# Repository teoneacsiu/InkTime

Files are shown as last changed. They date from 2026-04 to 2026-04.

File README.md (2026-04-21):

# InkTime

Smartwatch open-source bazat pe **nRF52840**, proiectat pentru cursul TSC. Acest repository contine partea de hardware, manufacturing si integrare mecanica pentru varianta **InkTime**.

---

## Structura repository-ului

```text
Hardware/
  - schematic (.sch)
  - board (.brd)

Manufacturing/
  - gerbers.zip
  - Bill of Materials (.bom / .csv)
  - Pick and Place (.cpl)

Mechanical/
  - ansamblu complet (.step)
  - fisierul Fusion360 al ansamblului complet

Images/
  - randari PCB
  - randari assembly
  - capturi schematic / board

LICENSE
README.md
```

---

## Stare proiect

- [x] structura repo
- [x] README completat
- [x] BOM de documentatie pentru componentele critice
- [x] schematic complet
- [x] ERC curat
- [x] board complet
- [x] DRC cu fisierul oficial
- [x] gerbers / BOM / CPL exportate
- [ ] model 3D complet: PCB + baterie + display + shaker + carcasa
- [ ] review DVT
- [ ] fix-uri pentru GNG

---

## Block diagram

```mermaid
flowchart LR
    USB[USB-C]
    ESD[USB ESD Protection]
    PMIC[BQ25180YBGR\nLi-Ion Charger + Power Path]
    DCDC[RT6160AWSC\nBuck-Boost 3V3]
    MCU[nRF52840\nBLE SoC]
    IMU[BMA421/BMA423\nAccelerometer]
    FG[MAX17048G+T10\nFuel Gauge]
    HAPTIC[DRV2605YZFR\nHaptic Driver]
    EPDPWR[E-Paper Power Stage]
    EPD[24-pin E-Paper FPC]
    BTN[3 Buttons]
    SWD[SWD Header / Test Pads]
    ANT[2.4 GHz Chip Antenna]
    BAT[Li-Po Battery]

    USB --> ESD --> MCU
    USB --> PMIC
    BAT --> PMIC
    BAT --> FG
    PMIC --> DCDC
    DCDC --> MCU
    DCDC --> IMU
    DCDC --> FG
    DCDC --> HAPTIC
    DCDC --> EPDPWR
    MCU <-->|I2C| IMU
    MCU <-->|I2C| PMIC
    MCU <-->|I2C| FG
    MCU <-->|I2C| HAPTIC
    MCU -->|SPI + control| EPDPWR
    EPDPWR --> EPD
    MCU --> BTN
    MCU --> SWD
    MCU --> ANT
```

---

## Arhitectura hardware

### 1. Microcontroller + radio
Controllerul principal este **nRF52840** in capsula QFN/AQFN, folosit pentru:
- controlul intregului sistem;
- comunicare BLE;
- interfata USB;
- I2C pentru PMIC / IMU / fuel gauge / haptic;
- SPI + semnale de control pentru display-ul e-paper;
- SWD pentru debug si programare.

Blocul radio foloseste:
- cristal de **32 MHz** pentru radio;
- cristal de **32.768 kHz** pentru timp real / low power;
- retea de adaptare RF;
- antena chip **2450AT18B100E**.

### 2. Alimentare
Alimentarea este impartita in doua etape:
- **BQ25180YBGR** pentru incarcarea bateriei Li-Po si power-path;
- **RT6160AWSC** pentru generarea tensiunii principale de **3V3**.

Aceasta separare permite:
- alimentare din USB;
- incarcare baterie;
- distributie stabila de 3V3 pentru MCU si periferice.

### 3. Senzori si periferice
- **BMA421/BMA423** - accelerometru low-power pentru detectie miscare / gesturi;
- **MAX17048G+T10** - fuel gauge pentru estimarea starii bateriei;
- **DRV2605YZFR** - driver haptic pentru feedback tactil;
- **E-paper connector + drive stage** - interfata catre display-ul principal;
- **3 butoane** - interfata fizica utilizator;
- **USB-C + ESD** - alimentare si comunicare USB.

---

## Interfete si mapare pini nRF52840

| Functie | Net / semnal | Pin nRF52840 | Motiv |
|---|---|---:|---|
| I2C data | SDA | P0.06 | magistrala comuna pentru PMIC, IMU, fuel gauge, haptic |
| I2C clock | SCL | P0.07 | magistrala comuna pentru PMIC, IMU, fuel gauge, haptic |
| PMIC interrupt | PMIC_INT | P0.11 | evenimente incarcare / power-path |
| IMU interrupt 1 | IMU_INT1 | P0.08 | semnal de intrerupere de la accelerometru |
| IMU interrupt 2 | IMU_INT2 | P1.08 | al doilea semnal de intrerupere de la accelerometru |
| Haptic enable / trigger | HAPTIC_EN | P0.12 | controlul driverului DRV2605 |
| Fuel gauge alert | ALERT | P0.10 / NFC2 | semnal alerta baterie / SOC |
| USB VBUS detect | VBUS | VBUS pin dedicat | detectare prezenta USB |
| USB data minus | D- | D- pin dedicat | USB 2.0 |
| USB data plus | D+ | D+ pin dedicat | USB 2.0 |
| Display chip select | EPD_CS | P0.05 | selectare SPI pentru e-paper |
| Display data/command | EPD_DC | P0.15 | diferentiere date/comenzi |
| Display busy | EPD_BUSY | P0.16 | status busy din display |
| Display reset | EPD_RST | P0.17 | reset hardware display |
| User button UP | SW_UP | P1.15 | input utilizator |
| User button ENTER | SW_ENT | P0.14 | input utilizator |
| User button DOWN | SW_DN | P1.02 | input utilizator |
| E-paper power enable | GPIO pentru Q1 | P1.01 | comanda alimentarea blocului e-paper |
| SWD data | SWDIO | SWDIO pin dedicat | debug/programare |
| SWD clock | SWDCLK | SWDCLK pin dedicat | debug/programare |
| Trace / debug | SWO | GPIO debug | punct de test pentru debugging |

### Observatii pe maparea pinilor
- Magistrala **I2C** este comuna si reduce numarul total de pini ocupati.
- Interfata USB foloseste pinii dedicati ai nRF52840 pentru compatibilitate corecta.
- Semnalele catre e-paper sunt separate intre control (`EPD_CS`, `EPD_DC`, `EPD_RST`, `EPD_BUSY`) si alimentare.
- Butoanele sunt conectate pe GPIO-uri separate pentru tratare simpla in firmware.
- Semnalele de debug sunt expuse atat prin conectorul SWD, cat si prin test pad-uri.

---

## Functionalitatea fiecarui bloc

### nRF52840
- MCU principal;
- BLE;
- USB FS;
- interfete I2C / SPI / GPIO;
- control low-power.

### BQ25180YBGR
- incarcare baterie Li-Ion/LiPo;
- power-path management;
- monitorizare si configurare prin I2C.

### RT6160AWSC
- buck-boost I2C-programmable;
- genereaza 3V3 din sursa sistemului;
- mentine tensiunea stabila pentru subsisteme.

### BMA421/BMA423
- accelerometru digital ultra-low-power;
- detectare miscare / activitate;
- intreruperi dedicate catre MCU.

### MAX17048G+T10
- fuel gauge pentru baterie LiPo;
- masoara tensiunea si estimeaza state-of-charge;
- alerta low battery catre MCU.

### DRV2605YZFR
- driver haptic pentru actuator ERM/LRA;
- controlabil prin I2C;
- permite feedback tactil complex.

### USB-C + ESD
- alimentare si date USB;
- rezistente de configurare CC;
- protectie ESD pe D+/D-/VBUS.

### E-paper drive + connector
- conector FPC de 24 pini;
- etapa de alimentare si comanda pentru display;
- linii SPI/control catre MCU.

---

## BOM de documentatie

BOM-ul de mai jos contine **componentele critice**. Pentru BOM-ul complet de productie trebuie folosit exportul din Fusion/EAGLE.

| RefDes | Componenta | MPN | Qty | Observatii |
|---|---|---|---:|---|
| U1 | BLE SoC | NRF52840-QIAA-R / QIAA-T | 1 | MCU principal |
| IC1 | Charger + power path | BQ25180YBGR | 1 | management baterie |
| IC9 | Buck-boost converter | RT6160AWSC | 1 | 3V3 principal |
| IC3 | IMU | BMA421 / BMA423 | 1 | biblioteca folosita contine BMA423 |
| U3 | Fuel gauge | MAX17048G+T10 | 1 | monitorizare baterie |
| IC2 | Haptic driver | DRV2605YZFR | 1 | control vibratii |
| J4 | USB-C | KH-TYPE-C-16P | 1 | alimentare + USB |
| D3 | ESD USB | USBLC6-2SC6Y | 1 | protectie D+/D-/VBUS |
| J1 | E-paper FPC | 503480-2400 | 1 | conector display |
| ANT1 | Chip antenna 2.4 GHz | 2450AT18B100E | 1 | BLE antenna |
| J2 | SWD header | TC2030-IDC | 1 | programare / debug |
| D2,D4,D5 | Schottky diode | MBR0530 | 3 | bloc power e-paper |
| Q3 | N-MOS | SI1308EDL-T1-GE3 | 1 | drive e-paper |
| Q1 | P-MOS | DMG2305UX-7 | 1 | comutare alimentare e-paper |
| X1 | RF crystal | 32MHz | 1 | ceas radio |
| X2 | RTC crystal | 32.768kHz | 1 | low-power timing |
| L7 | Inductor DCDC | FTC252012SR47MBCA | 1 | buck-boost RT6160 |
| SW_UP, SW_ENT, SW_DN | Butoane tactile | TBD | 3 | verificare finala dupa layout |
| Battery | Li-Po battery | TBD | 1 | model 3D de desenat |
| Display | E-paper module | TBD | 1 | model 3D de desenat |
| Shaker | ERM/LRA actuator | TBD | 1 | model 3D de desenat |

### Observatii BOM
- Toate rezistentele sunt SMD 0201.
- Toate condensatoarele cu valori `<= 100nF` sunt SMD 0201.
- Condensatoarele cu valori `> 100nF` sunt 0402, cu exceptiile specificate explicit in schema.
- BOM-ul din README este un BOM de documentatie; BOM-ul final de productie va fi exportat direct din CAD.

---

## Design rules si constrangeri care trebuie respectate

### PCB / mechanical
- grosime PCB: **1.0 mm**;
- componentele se amplaseaza **exclusiv pe TOP**;
- rutarea poate fi pe TOP si BOTTOM;
- trebuie **plan de masa pe TOP si pe BOTTOM**;
- daca se folosesc 4 straturi, unul dintre straturile interne trebuie sa fie GND;
- PCB-ul trebuie sa intre in carcasa furnizata;
- USB-C, butoanele si conectorul display trebuie aliniate mecanic cu carcasa.

### RF
- antena trebuie plasata spre exteriorul placii;
- sub antena **nu se pune plan de masa**;
- sub antena **nu se routeaza semnale**;
- se recomanda via stitching in jurul planurilor de GND, in special in zona radio.

### Routing
- trasee de putere: **0.30 mm**;
- trasee de semnal: **minim 0.15 mm**;
- fara unghiuri de 90°;
- se evita vias pe traseele de putere, pe cat posibil;
- condensatoarele de 100nF trebuie puse cat mai aproape de pinii de alimentare.

### Verificari
- ERC obligatoriu;
- DRC obligatoriu cu fisierul de reguli din arhiva;
- eroarea **Only INPUT pins on NET ID** poate fi ignorata;
- erorile de **Dimension** cauzate de butoane si USB pot fi justificate conform cerintei.

### Silkscreen
- silkscreen-ul trebuie sa fie lizibil;
- pe silkscreen se pastreaza **numele componentelor**, nu valorile;
- test pad-urile trebuie marcate clar cu numele semnalelor.

---

## Packaging si reguli de selectie a pasivelor

Conform cerintei:
- toate rezistentele sunt SMD **0201**;
- condensatoarele cu valori **<= 100nF** sunt **0201**;
- condensatoarele cu valori **> 100nF** sunt **0402**, cu exceptiile specificate explicit in schema.

---

## Manufacturing outputs

La final, repository-ul trebuie sa contina:

### Hardware
- `InkTime.sch`
- `InkTime.brd`

### Manufacturing
- `gerbers.zip`
- `InkTime.bom` / `BOM.csv`
- `InkTime.cpl`

### Mechanical
- ansamblu complet `STEP`
- fisierul Fusion360 al ansamblului complet

### Images
- randare PCB top
- randare PCB bottom
- randare assembly complet
- capturi schematic / board

---

## Design log / decizii

### Decizii luate pana acum
- biblioteca utilizata: `InkTime_v5.lbr`;
- schema este implementata dupa modelul furnizat;
- pentru IMU se foloseste simbolul / footprint-ul disponibil in biblioteca (**BMA423**), urmand sa fie mentionat explicit in review si in BOM;
- BOM-ul din README este unul de documentatie; BOM-ul final de asamblare va fi exportat direct din CAD;
- retelele critice de alimentare si RF au fost pastrate compacte pentru a facilita routarea si respectarea constrangerilor de layout.

### Probleme / aspecte de urmarit
- verificarea disponibilitatii finale la JLC pentru toate componentele critice;
- confirmarea exacta a modelului de baterie, display si shaker;
- verificarea finala a footprint-urilor pentru componentele foarte mici (WLCSP / DSBGA / AQFN);
- justificarea eventualelor erori DRC/Dimension acceptate conform cerintei;
- completarea integrarii mecanice 3D a bateriei, display-ului si actuatorului haptic.

---

## Imagini

Imaginile finale vor fi puse in `Images/`:
- `pcb_top.png`
- `pcb_bottom.png`
- `assembly_render.png`
- `schematic_page1.png`
- `schematic_page2.png`

---

## Limitari curente

In momentul actual, partea de proiectare electrica si de PCB este considerata finalizata la nivel de documentatie, iar partea ramasa de completat este integrarea 3D completa:
- modelul 3D al bateriei;
- modelul 3D al display-ului e-paper;
- modelul 3D al shaker-ului;
- verificarea finala a ansamblului complet in carcasa.

Toate celelalte livrabile hardware si de manufacturing sunt pregatite la nivel de repository si documentatie.

---

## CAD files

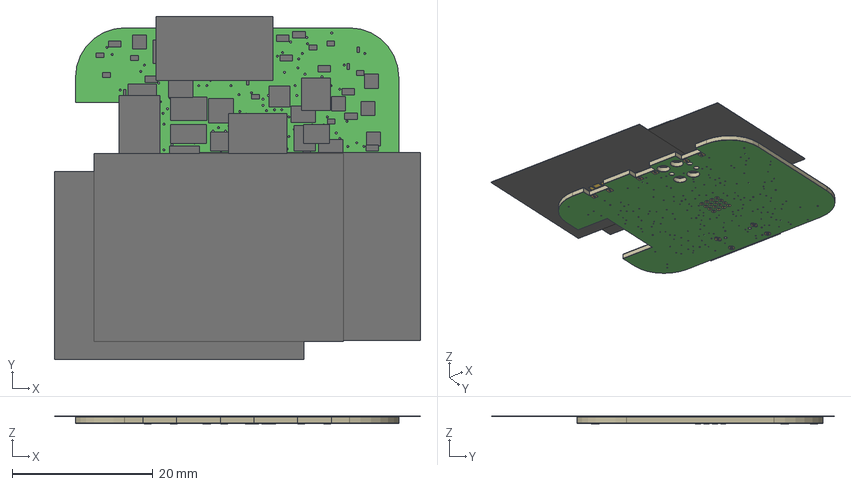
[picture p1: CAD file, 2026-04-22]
Mechanical/InkTime_complete_assembly.step
52.1 x 48.8 x 1.15 mm

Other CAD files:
Mechanical/InkTime_complete_assembly.f3d

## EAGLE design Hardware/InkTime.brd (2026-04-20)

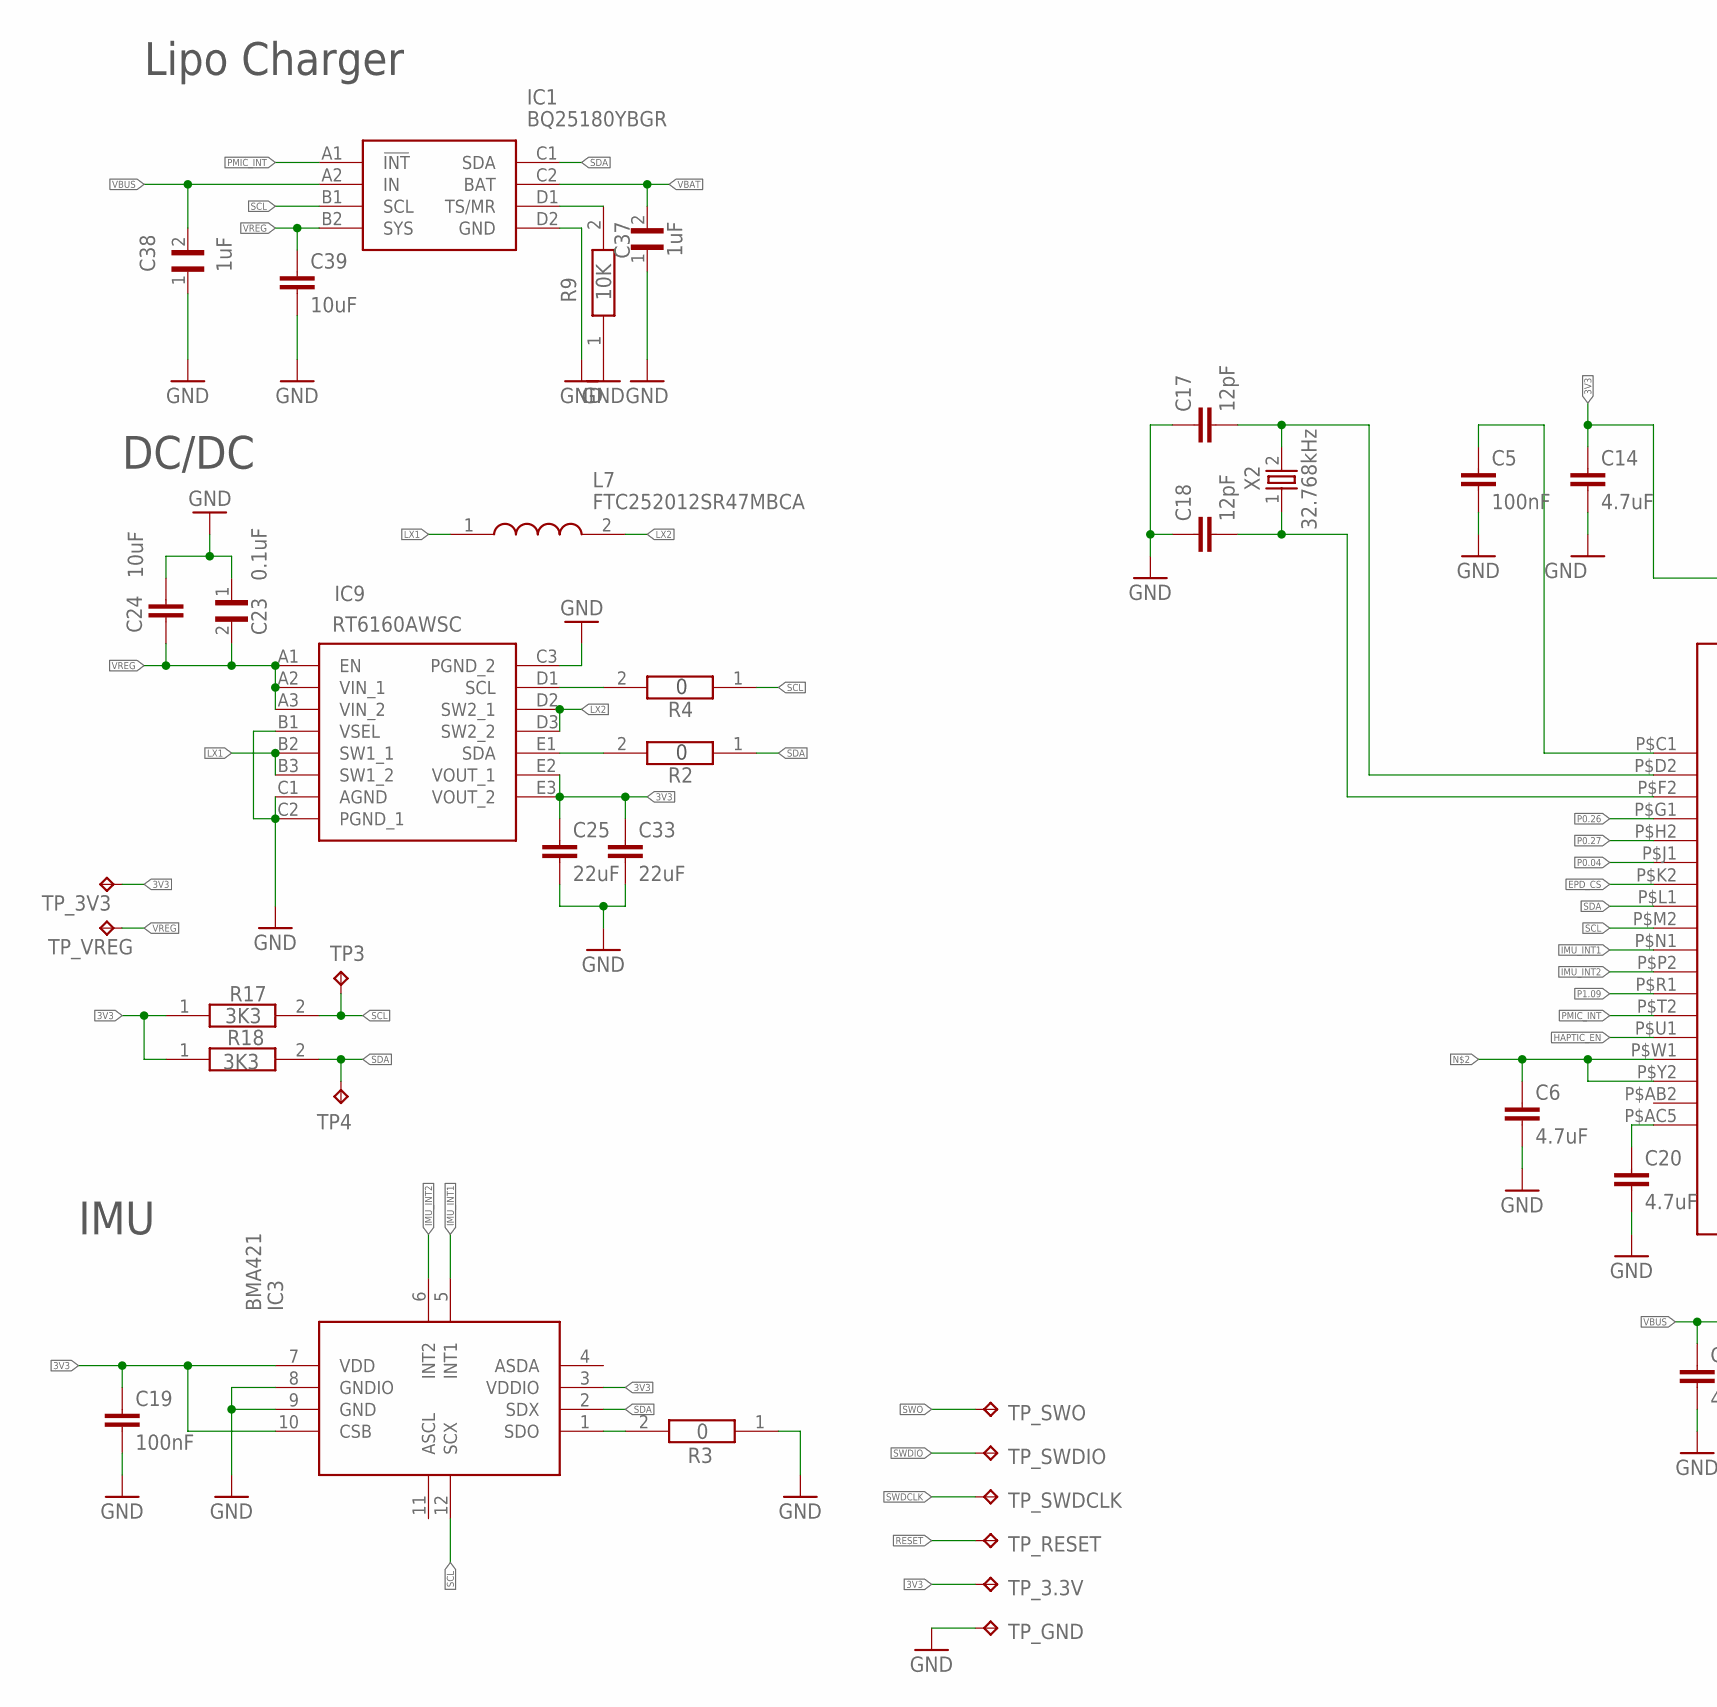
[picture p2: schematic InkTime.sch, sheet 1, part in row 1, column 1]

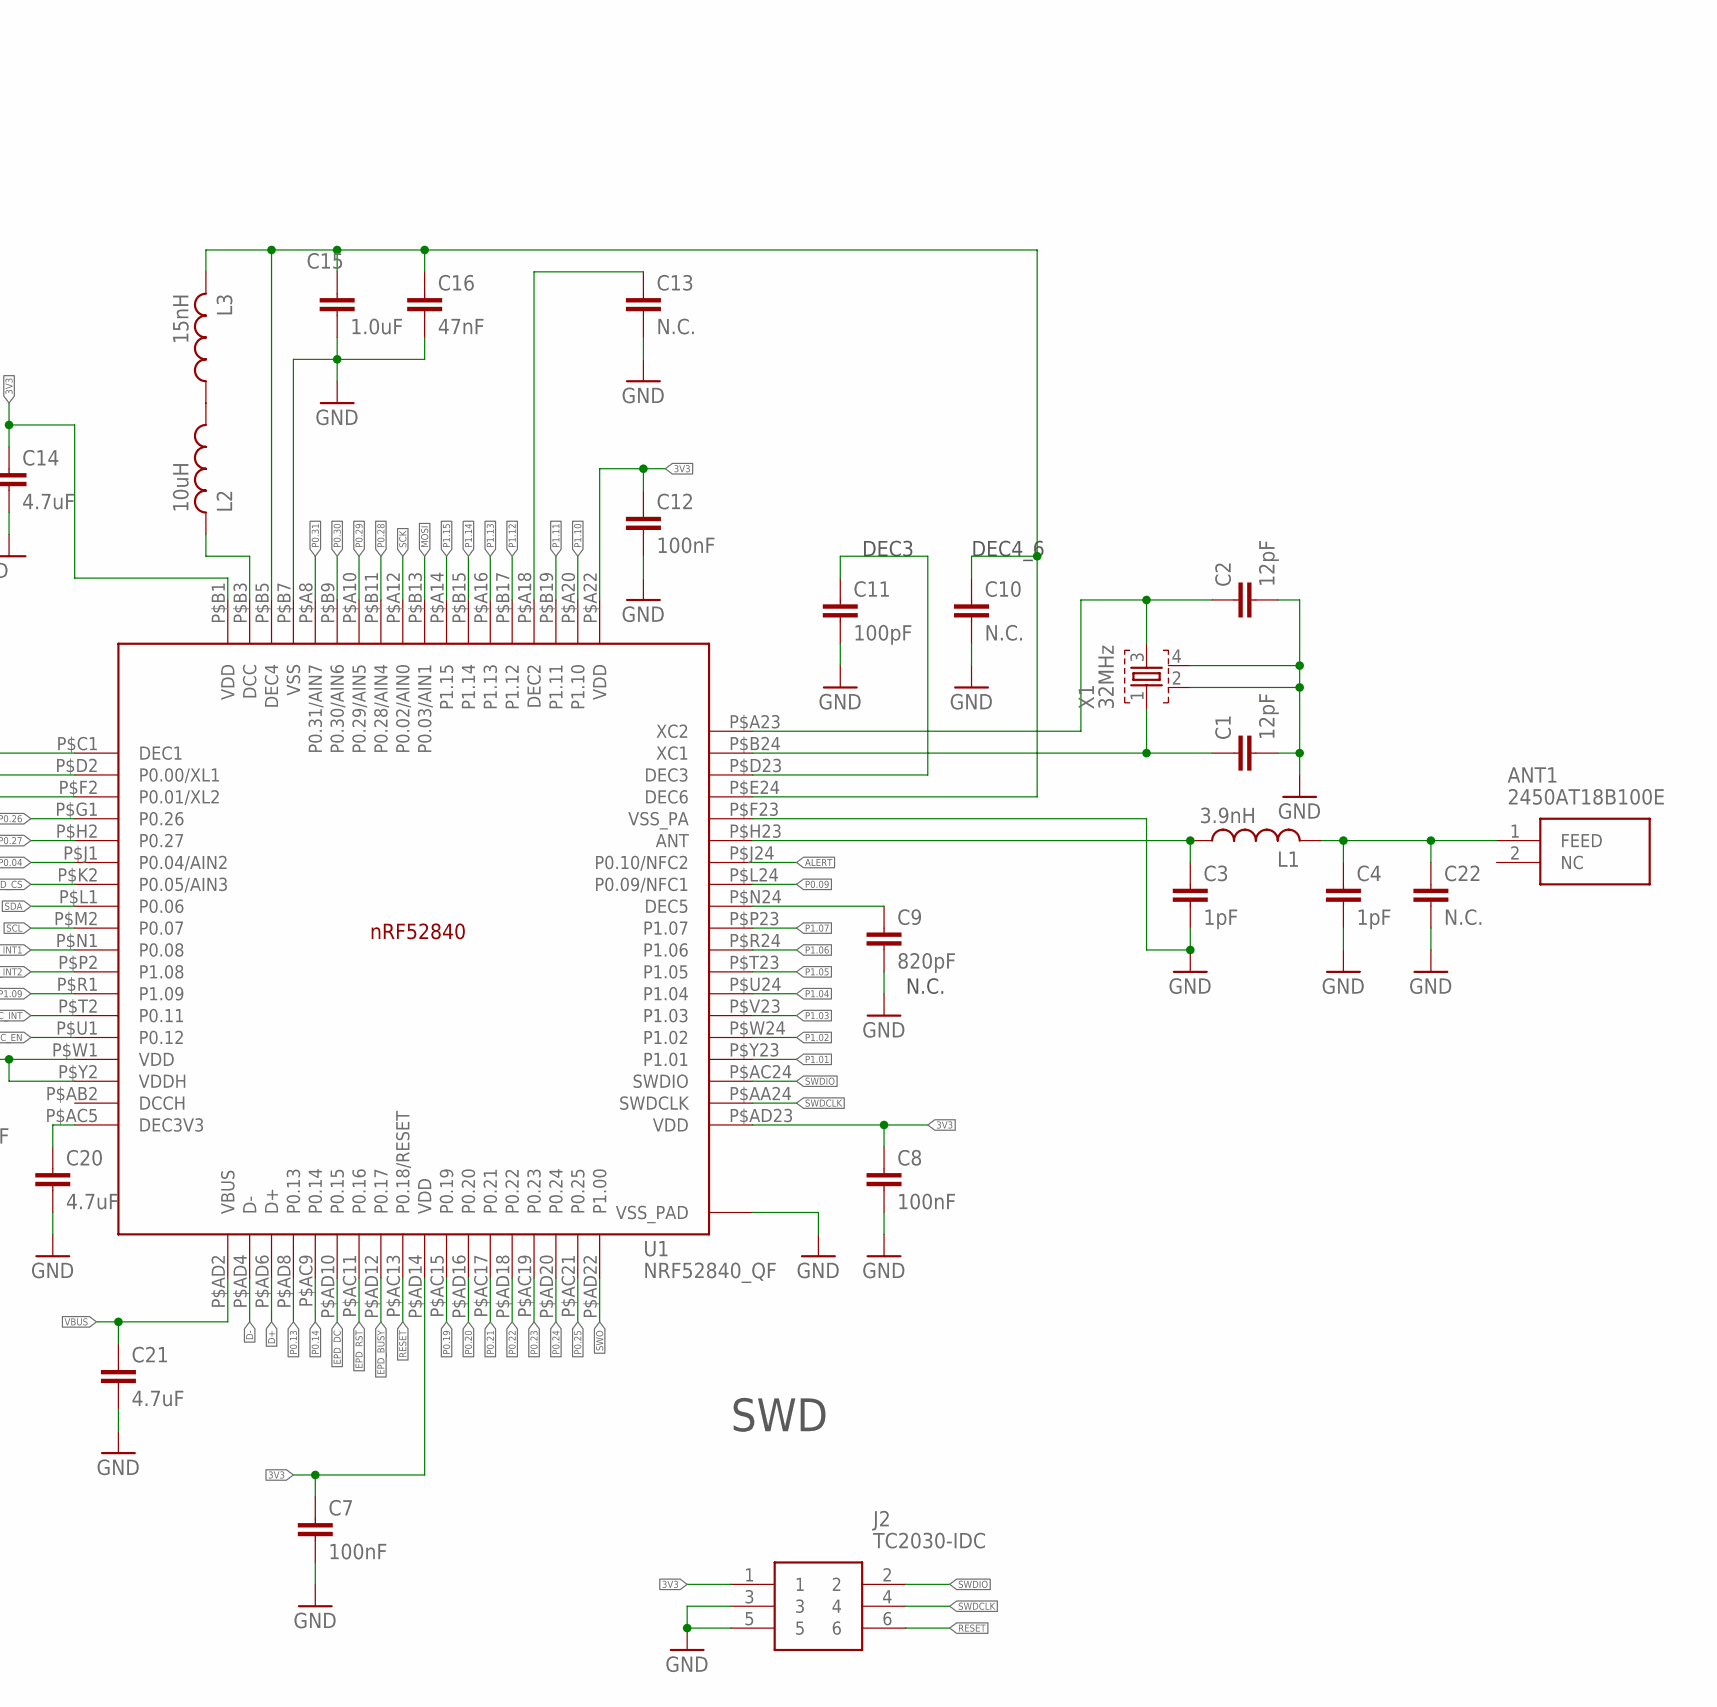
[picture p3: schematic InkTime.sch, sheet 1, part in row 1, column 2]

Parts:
ANT1: 2450AT18B100E; 2450AT18B100E_ANTC3216X140N
C1, C2, C17, C18: 12pF; NORDIC_NRF_3_RESC0201_L
C3, C4: 1pF; NORDIC_NRF_3_RESC0201_L
C5, C7, C8, C12, C19: 100nF; NORDIC_NRF_3_RESC0402_L
C6, C14, C20, C21: 4.7uF; NORDIC_NRF_3_RESC0402_L
C9: 820pF; NORDIC_NRF_3_RESC0201_L
C10, C13, C22: N.C.; NORDIC_NRF_3_RESC0201_L
C11: 100pF; NORDIC_NRF_3_RESC0201_L
C15: 1.0uF; NORDIC_NRF_3_RESC0402_L
C16: 47nF; NORDIC_NRF_3_RESC0201_L
C23: 0.1uF; GRM011R60J152KE01L_2_CAPC0201X13N
C24: 10uF; NORDIC_NRF_3_RESC0201_L
C25, C33: 22uF; NORDIC_NRF_3_RESC0402_L
C37, C38: 1uF; GRM011R60J152KE01L_2_CAPC0201X13N
C39: 10uF; NORDIC_NRF_3_RESC0402_L
IC1: BQ25180YBGR; BQ25180YBGR_BGA8C40P2X4_100X155X50
IC3: BMA421; BMA423_BMA423
IC9: RT6160AWSC; RT6160AWSC_BGA15C40P3X5_140X230X60
J2: TC2030-IDC; TC2030-IDC_TC2030IDC
L1: 3.9nH; NORDIC_NRF_2_RESC0402_L
L2: 10uH; NORDIC_NRF_2_RESC0402_L
L3: 15nH; NORDIC_NRF_2_RESC0201_L
L7: FTC252012SR47MBCA; MLP2016SR47MT0S1_INDC2016X100N
R2, R4: 0; CPF0201D7K68C1_0201
R3: 0; ERA-1AEB3401C_0201
R9: 10K; CPF0201D7K68C1_0201
R17, R18: 3K3; CPF0201D7K68C1_0201
TP3, TP4: HECTOR_WATCH_1_TPTP20R; HECTOR_WATCH_1_TP20R
TP_3.3V, TP_3V3: HECTOR_WATCH_1_TPTP20R; HECTOR_WATCH_1_TP20R
TP_GND: HECTOR_WATCH_1_TPTP20R; HECTOR_WATCH_1_TP20R
TP_RESET: HECTOR_WATCH_1_TPTP20R; HECTOR_WATCH_1_TP20R
TP_SWDCLK: HECTOR_WATCH_1_TPTP20R; HECTOR_WATCH_1_TP20R
TP_SWDIO: HECTOR_WATCH_1_TPTP20R; HECTOR_WATCH_1_TP20R
TP_SWO: HECTOR_WATCH_1_TPTP20R; HECTOR_WATCH_1_TP20R
TP_VREG: HECTOR_WATCH_1_TPTP20R; HECTOR_WATCH_1_TP20R
U1: NRF52840_QF; NORDIC_NRF_4_AQFN50P700X700X85_HS-74N
X1: 32MHz; NORDIC_NRF_BT-XTAL_2016_N
X2: 32.768kHz; NORDIC_NRF_1_XTAL_3215_N

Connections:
3V3: C7.1, C8.1, C12.1, C14.1, C19.1, C25.1, C33.1, IC3.3 (VDDIO), IC3.7 (VDD), IC3.10 (CSB), IC9.E2 (VOUT_1), IC9.E3 (VOUT_2), J2.1, R17.1, R18.1, TP_3.3V.TP, TP_3V3.TP, U1.P$A22 (VDD), U1.P$AD14 (VDD), U1.P$AD23 (VDD), U1.P$B1 (VDD); also elsewhere on the board
ALERT: U1.P$J24 (P0.10/NFC2); also elsewhere on the board
D+: U1.P$AD6 (D+); also elsewhere on the board
D-: U1.P$AD4 (D-); also elsewhere on the board
EPD_BUSY: U1.P$AD12 (P0.17); also elsewhere on the board
EPD_CS: U1.P$K2 (P0.05/AIN3); also elsewhere on the board
EPD_DC: U1.P$AD10 (P0.15); also elsewhere on the board
EPD_RST: U1.P$AC11 (P0.16); also elsewhere on the board
GND: C1.2, C2.2, C3.2, C4.2, C5.2, C6.2, C7.2, C8.2, C9.2, C10.2, C11.2, C12.2, C13.2, C14.2, C15.2, C16.2, C17.1, C18.1, C19.2, C20.2, C21.2, C22.2, C23.1, C24.1, C25.2, C33.2, C37.1, C38.1, C39.2, IC1.D2 (GND), IC3.8 (GNDIO), IC3.9 (GND), IC9.B1 (VSEL), IC9.C1 (AGND), IC9.C2 (PGND_1), IC9.C3 (PGND_2), J2.3, J2.5, R3.1, R9.1, TP_GND.TP, U1.P$74 (VSS_PAD), U1.P$75 (VSS_PAD), U1.P$76 (VSS_PAD), U1.P$77 (VSS_PAD), U1.P$78 (VSS_PAD), U1.P$79 (VSS_PAD), U1.P$80 (VSS_PAD), U1.P$81 (VSS_PAD), U1.P$82 (VSS_PAD), U1.P$83 (VSS_PAD), U1.P$84 (VSS_PAD), U1.P$85 (VSS_PAD), U1.P$86 (VSS_PAD), U1.P$87 (VSS_PAD), U1.P$88 (VSS_PAD), U1.P$89 (VSS_PAD), U1.P$90 (VSS_PAD), U1.P$B7 (VSS), U1.P$F23 (VSS_PA), X1.2, X1.4; also elsewhere on the board
HAPTIC_EN: U1.P$U1 (P0.12); also elsewhere on the board
IMU_INT1: IC3.5 (INT1), U1.P$N1 (P0.08)
IMU_INT2: IC3.6 (INT2), U1.P$P2 (P1.08)
LX1: IC9.B2 (SW1_1), IC9.B3 (SW1_2), L7.1
LX2: IC9.D2 (SW2_1), IC9.D3 (SW2_2), L7.2
MOSI: U1.P$B13 (P0.03/AIN1); also elsewhere on the board
unnamed: IC1.D1 (TS/MR), R9.2
unnamed: C6.1, U1.P$W1 (VDD), U1.P$Y2 (VDDH)
unnamed: C17.2, U1.P$D2 (P0.00/XL1), X2.2
unnamed: C20.1, U1.P$AC5 (DEC3V3)
unnamed: C18.2, U1.P$F2 (P0.01/XL2), X2.1
unnamed: C5.1, U1.P$C1 (DEC1)
unnamed: IC9.D1 (SCL), R4.2
unnamed: ANT1.1 (FEED), C4.1, C22.1, L1.2
unnamed: IC9.E1 (SDA), R2.2
unnamed: L2.2, U1.P$B3 (DCC)
unnamed: C13.1, U1.P$A18 (DEC2)
unnamed: C2.1, U1.P$A23 (XC2), X1.3
unnamed: C1.1, U1.P$B24 (XC1), X1.1
unnamed: C11.1, U1.P$D23 (DEC3)
unnamed: C10.1, C15.1, C16.1, L3.2, U1.P$B5 (DEC4), U1.P$E24 (DEC6)
unnamed: C3.1, L1.1, U1.P$H23 (ANT)
unnamed: C9.1, U1.P$N24 (DEC5)
unnamed: IC3.1 (SDO), R3.2
unnamed: L2.1, L3.1
P0.04: U1.P$J1 (P0.04/AIN2)
P0.09: U1.P$L24 (P0.09/NFC1)
P0.13: U1.P$AD8 (P0.13); also elsewhere on the board
P0.14: U1.P$AC9 (P0.14); also elsewhere on the board
P0.19: U1.P$AC15 (P0.19)
P0.20: U1.P$AD16 (P0.20)
P0.21: U1.P$AC17 (P0.21)
P0.22: U1.P$AD18 (P0.22)
P0.23: U1.P$AC19 (P0.23)
P0.24: U1.P$AD20 (P0.24)
P0.25: U1.P$AC21 (P0.25)
P0.26: U1.P$G1 (P0.26)
P0.27: U1.P$H2 (P0.27)
P0.28: U1.P$B11 (P0.28/AIN4)
P0.29: U1.P$A10 (P0.29/AIN5)
P0.30: U1.P$B9 (P0.30/AIN6)
P0.31: U1.P$A8 (P0.31/AIN7)
P1.01: U1.P$Y23 (P1.01); also elsewhere on the board
P1.02: U1.P$W24 (P1.02); also elsewhere on the board
P1.03: U1.P$V23 (P1.03)
P1.04: U1.P$U24 (P1.04)
P1.05: U1.P$T23 (P1.05)
P1.06: U1.P$R24 (P1.06)
P1.07: U1.P$P23 (P1.07)
P1.09: U1.P$R1 (P1.09)
P1.10: U1.P$A20 (P1.10)
P1.11: U1.P$B19 (P1.11)
P1.12: U1.P$B17 (P1.12)
P1.13: U1.P$A16 (P1.13)
P1.14: U1.P$B15 (P1.14)
P1.15: U1.P$A14 (P1.15)
PMIC_INT: IC1.A1 (!INT), U1.P$T2 (P0.11)
RESET: J2.6, TP_RESET.TP, U1.P$AC13 (P0.18/RESET)
SCK: U1.P$A12 (P0.02/AIN0); also elsewhere on the board
SCL: IC1.B1 (SCL), IC3.12 (SCX), R4.1, R17.2, TP3.TP, U1.P$M2 (P0.07); also elsewhere on the board
SDA: IC1.C1 (SDA), IC3.2 (SDX), R2.1, R18.2, TP4.TP, U1.P$L1 (P0.06); also elsewhere on the board
SWDCLK: J2.4, TP_SWDCLK.TP, U1.P$AA24 (SWDCLK)
SWDIO: J2.2, TP_SWDIO.TP, U1.P$AC24 (SWDIO)
SWO: TP_SWO.TP, U1.P$AD22 (P1.00)
VBAT: C37.2, IC1.C2 (BAT); also elsewhere on the board
VBUS: C21.1, C38.2, IC1.A2 (IN), U1.P$AD2 (VBUS); also elsewhere on the board
VREG: C23.2, C24.2, C39.1, IC1.B2 (SYS), IC9.A1 (EN), IC9.A2 (VIN_1), IC9.A3 (VIN_2), TP_VREG.TP

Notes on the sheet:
Lipo Charger
N.C.
DC/DC
IMU
DEC3
DEC4_6
SWD

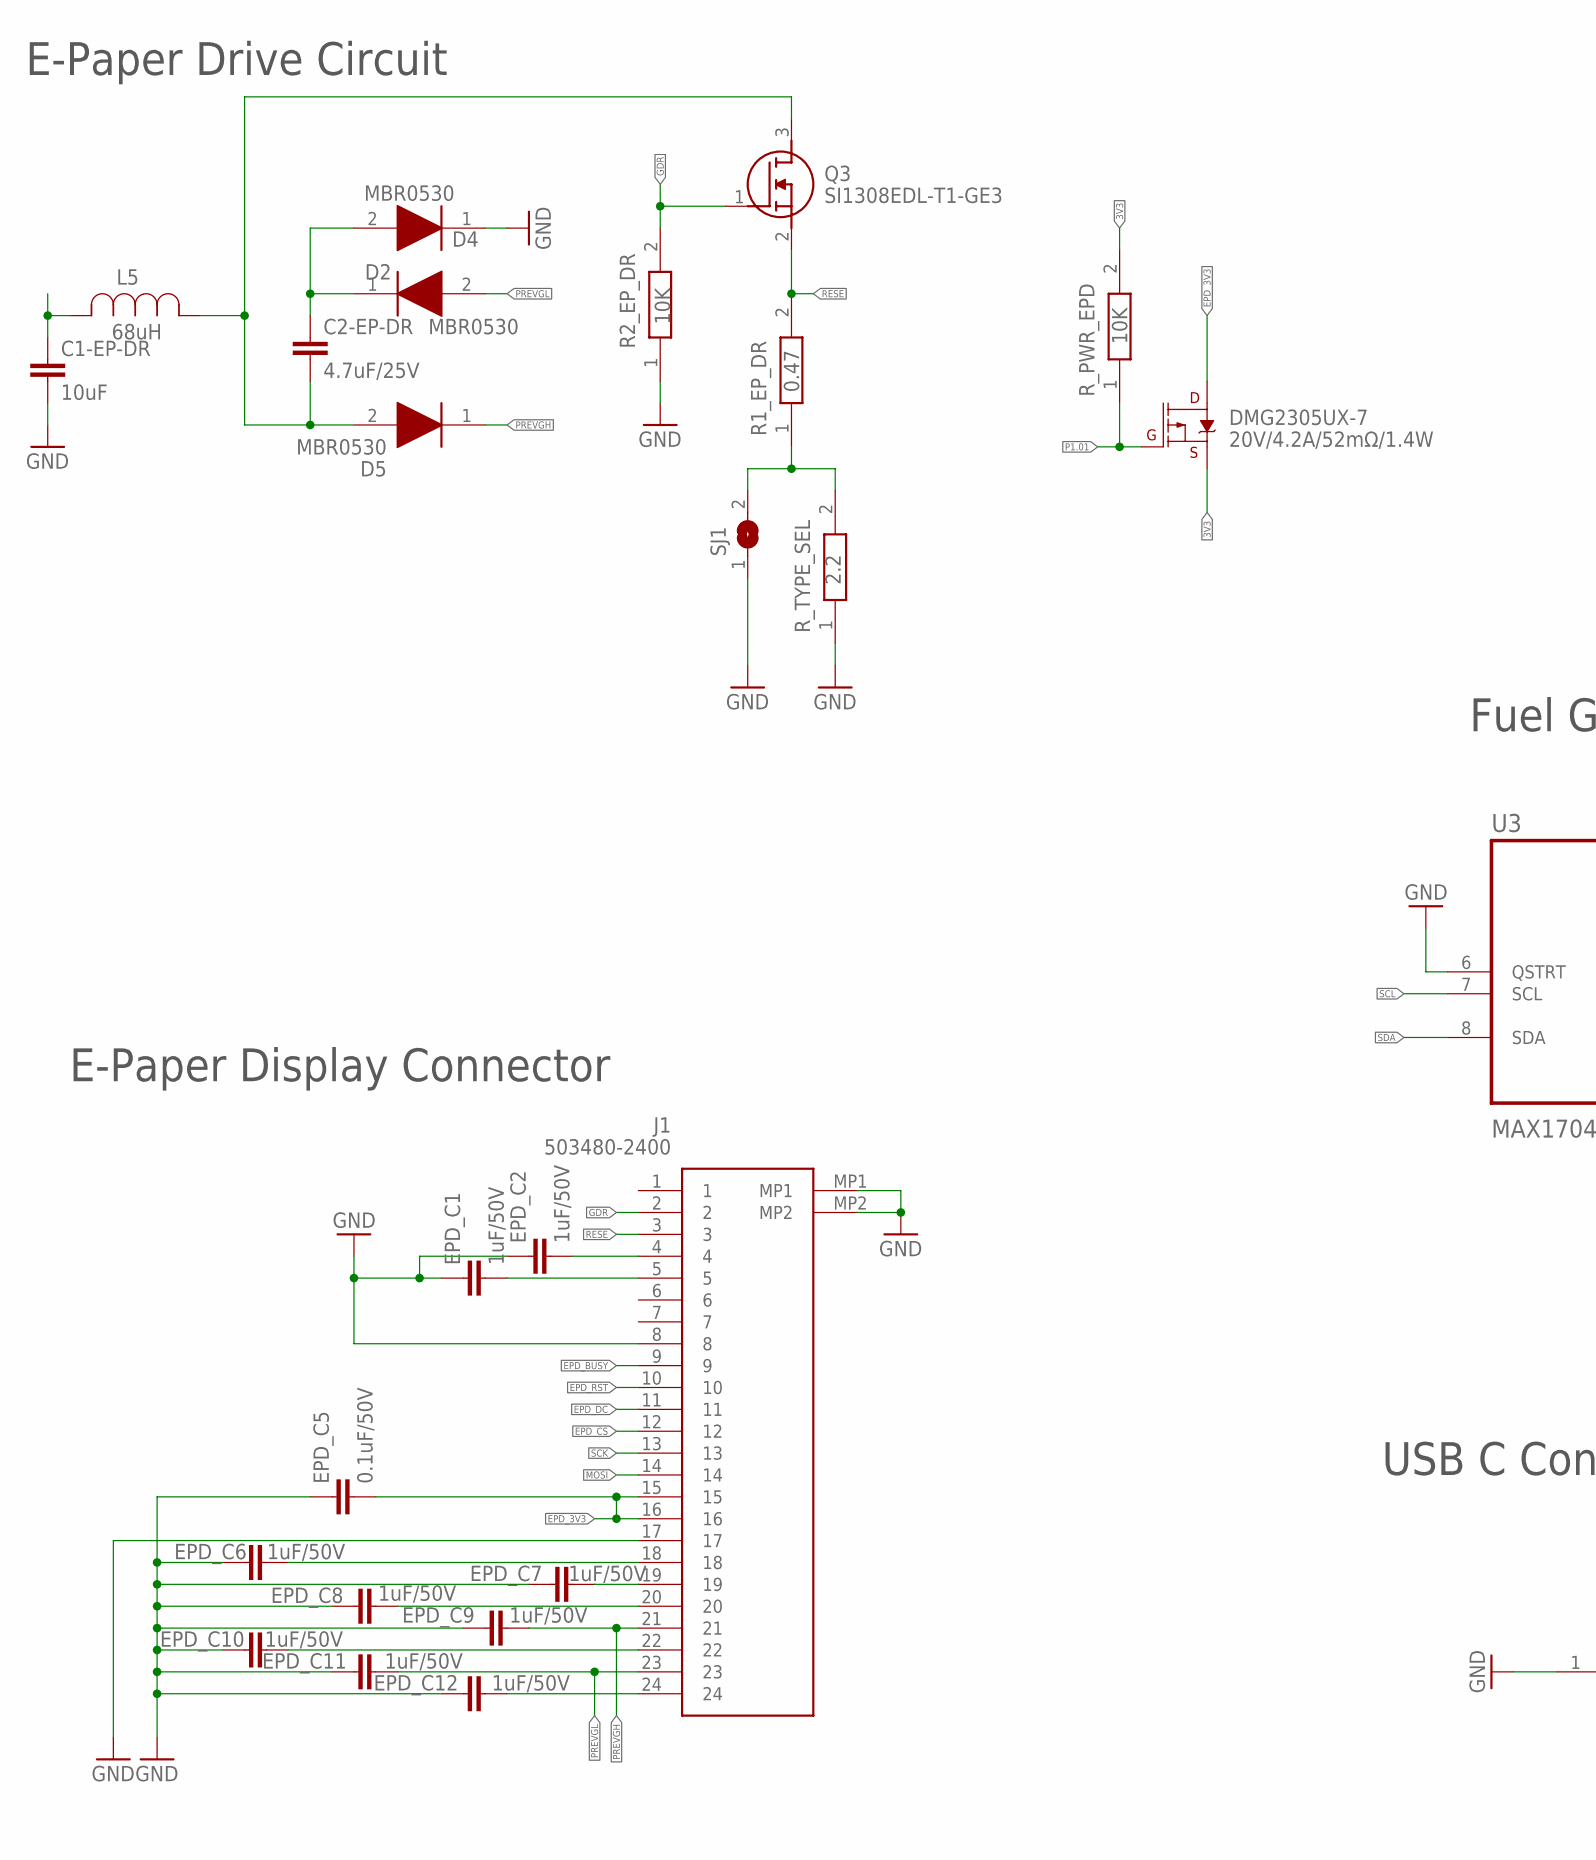
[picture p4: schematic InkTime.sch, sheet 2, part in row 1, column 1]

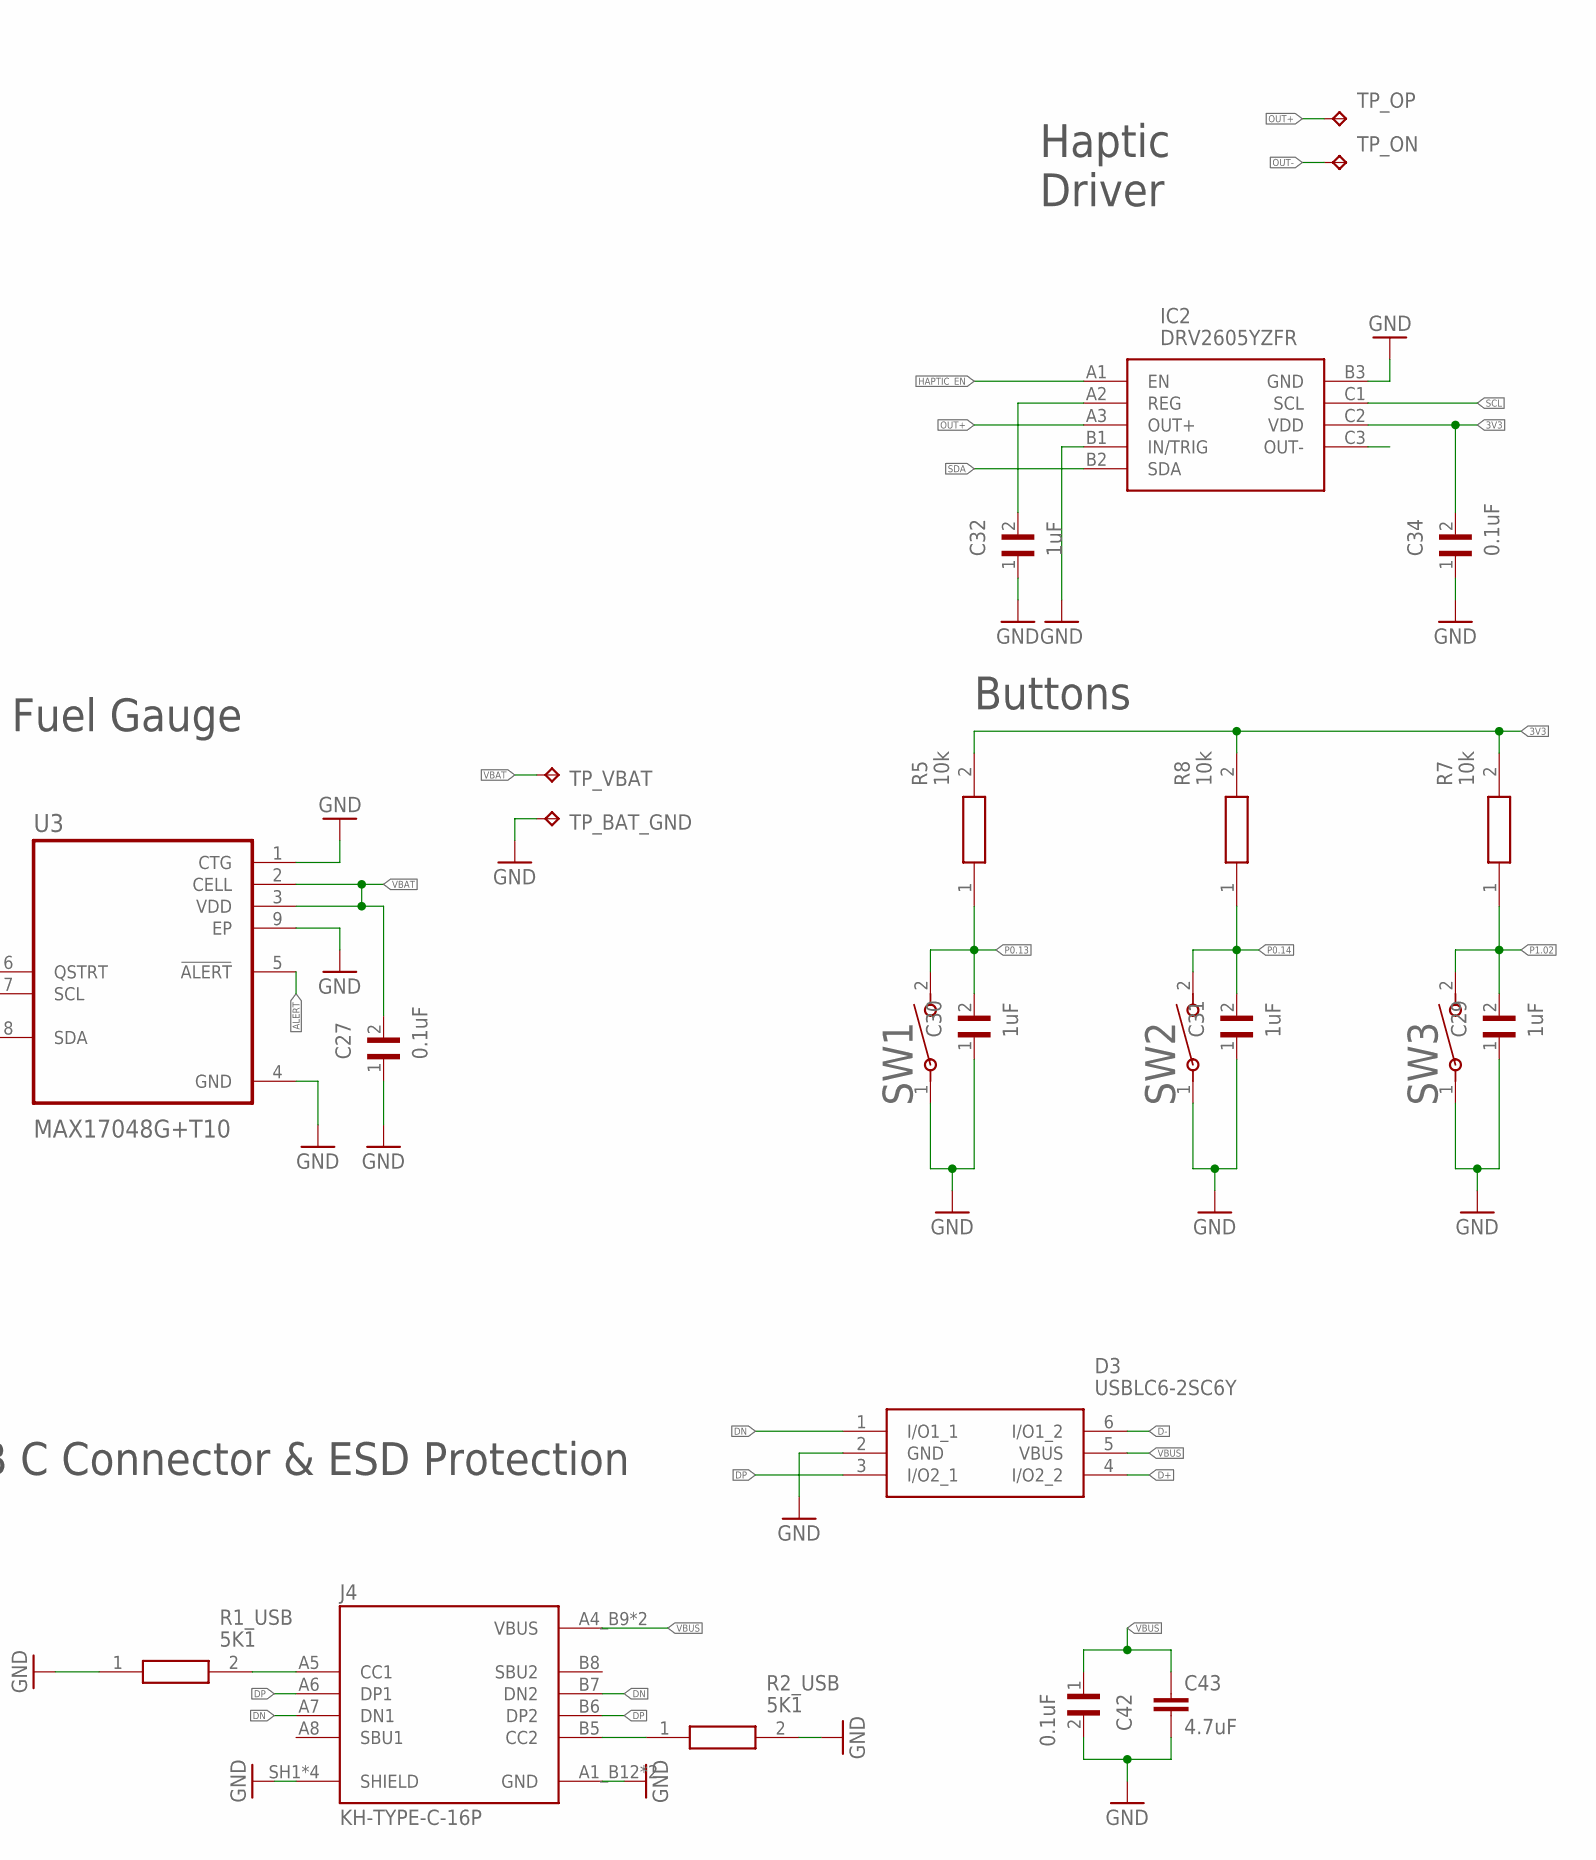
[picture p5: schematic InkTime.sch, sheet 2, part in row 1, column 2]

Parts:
C1-EP-DR: 10uF; NORDIC_NRF_3_RESC0402_L
C2-EP-DR: 4.7uF/25V; NORDIC_NRF_3_RESC0402_L
C27, C34, C42: 0.1uF; GRM011R60J152KE01L_2_CAPC0201X13N
C29, C30, C31, C32: 1uF; GRM011R60J152KE01L_2_CAPC0201X13N
C43: 4.7uF; NORDIC_NRF_3_RESC0402_L
D2, D4, D5: MBR0530; ESP32_C6_LIBRARY_5_SOD3716X135N
D3: USBLC6-2SC6Y; ESP32_C6_LIBRARY_3_SOT95P280X145-6N
DMG2305UX-7: 20V/4.2A/52mΩ/1.4W; ESP32_C6_LIBRARY_4_ESP32_C6_LIBRARY_4_ESP32_C6_LIBRARY_4_ES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
EPD_C1, EPD_C2, EPD_C6, EPD_C7, EPD_C8, EPD_C9, EPD_C10, EPD_C11, EPD_C12: 1uF/50V; NORDIC_NRF_3_RESC0402_L
EPD_C5: 0.1uF/50V; NORDIC_NRF_3_RESC0402_L
IC2: DRV2605YZFR; DRV2605YZFR_BGA9C50P3X3_144X144X62
J1: 503480-2400; 503480-2400_5034802400
J4: KH-TYPE-C-16P; KH-TYPE-C-16P_KINGHELM_KH-TYPE-C-16P
L5: 68uH; ESP32_C6_LIBRARY_2_IND_4828-WE-TPC_WRE
Q3: SI1308EDL-T1-GE3; ESP32_C6_LIBRARY_6_SOT65P210X110-3N
R1_EP_DR: 0.47; CPF0201D7K68C1_0201
R1_USB, R2_USB: 5K1; CPF0201D7K68C1_0201
R2_EP_DR: 10K; CPF0201D7K68C1_0201
R5, R7, R8: 10k; CPF0201D7K68C1_0201
R_PWR_EPD: 10K; CPF0201D7K68C1_0201
R_TYPE_SEL: 2.2; CPF0201D7K68C1_0201
SJ1: ESP32_C6_LIBRARY_7_JUMPER_SJ
SW1, SW2, SW3: 2025-10-22_07-23-44_LIBRARY_EVP-AKE31ASW_EVP-AKE3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; 2025-10-22_07-23-44_LIBRARY_SW_EVP-AKE31A_PAN
TP_BAT_GND: HECTOR_WATCH_1_TPTP20R; HECTOR_WATCH_1_TP20R
TP_ON: HECTOR_WATCH_1_TPTP20R; HECTOR_WATCH_1_TP20R
TP_OP: HECTOR_WATCH_1_TPTP20R; HECTOR_WATCH_1_TP20R
TP_VBAT: HECTOR_WATCH_1_TPTP20R; HECTOR_WATCH_1_TP20R
U3: MAX17048G+T10; ESP32_C6_LIBRARY_SON50P200X200X80-9N

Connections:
3V3: C34.2, DMG2305UX-7.2 (S), IC2.C2 (VDD), R5.2, R7.2, R8.2, R_PWR_EPD.2; also elsewhere on the board
ALERT: U3.5 (!ALERT); also elsewhere on the board
D+: D3.4 (I/O2_2); also elsewhere on the board
D-: D3.6 (I/O1_2); also elsewhere on the board
DN: D3.1 (I/O1_1), J4.A7 (DN1), J4.B7 (DN2)
DP: D3.3 (I/O2_1), J4.A6 (DP1), J4.B6 (DP2)
EPD_3V3: DMG2305UX-7.3 (D), EPD_C5.2, J1.15, J1.16
EPD_BUSY: J1.9; also elsewhere on the board
EPD_CS: J1.12; also elsewhere on the board
EPD_DC: J1.11; also elsewhere on the board
EPD_RST: J1.10; also elsewhere on the board
GDR: J1.2, Q3.1 (G), R2_EP_DR.2
GND: C1-EP-DR.2, C27.1, C29.1, C30.1, C31.1, C32.1, C34.1, C42.2, C43.2, D3.2 (GND), D4.1 (K), EPD_C1.1, EPD_C2.1, EPD_C5.1, EPD_C6.1, EPD_C7.2, EPD_C8.2, EPD_C9.2, EPD_C10.1, EPD_C11.2, EPD_C12.2, IC2.B1 (IN/TRIG), IC2.B3 (GND), J1.8, J1.17, J1.MP1, J1.MP2, J4.A1_B12 (GND), J4.A12_B1 (GND), J4.SH1 (SHIELD), J4.SH2 (SHIELD), J4.SH3 (SHIELD), J4.SH4 (SHIELD), R1_USB.1, R2_EP_DR.1, R2_USB.2, R_TYPE_SEL.1, SJ1.1, SW1.1, SW2.1, SW3.1, TP_BAT_GND.TP, U3.1 (CTG), U3.4 (GND), U3.6 (QSTRT), U3.9 (EP); also elsewhere on the board
HAPTIC_EN: IC2.A1 (EN); also elsewhere on the board
MOSI: J1.14; also elsewhere on the board
unnamed: C1-EP-DR.1, L5.2
unnamed: C2-EP-DR.2, D5.2 (A), L5.1, Q3.3 (D)
unnamed: C2-EP-DR.1, D2.1 (K), D4.2 (A)
unnamed: R1_EP_DR.1, R_TYPE_SEL.2, SJ1.2
unnamed: EPD_C2.2, J1.4
unnamed: EPD_C1.2, J1.5
unnamed: EPD_C6.2, J1.18
unnamed: EPD_C7.1, J1.19
unnamed: EPD_C8.1, J1.20
unnamed: C32.2, IC2.A2 (REG)
unnamed: J4.A5 (CC1), R1_USB.2
unnamed: EPD_C10.2, J1.22
unnamed: EPD_C12.1, J1.24
unnamed: J4.B5 (CC2), R2_USB.1
OUT+: IC2.A3 (OUT+), TP_OP.TP
OUT-: TP_ON.TP
P0.13: C30.2, R5.1, SW1.2; also elsewhere on the board
P0.14: C31.2, R8.1, SW2.2; also elsewhere on the board
P1.01: DMG2305UX-7.1 (G), R_PWR_EPD.1; also elsewhere on the board
P1.02: C29.2, R7.1, SW3.2; also elsewhere on the board
PREVGH: D5.1 (K), EPD_C9.1, J1.21
PREVGL: D2.2 (A), EPD_C11.1, J1.23
RESE: J1.3, Q3.2 (S), R1_EP_DR.2
SCK: J1.13; also elsewhere on the board
SCL: IC2.C1 (SCL), U3.7 (SCL); also elsewhere on the board
SDA: IC2.B2 (SDA), U3.8 (SDA); also elsewhere on the board
VBAT: C27.2, TP_VBAT.TP, U3.2 (CELL), U3.3 (VDD); also elsewhere on the board
VBUS: C42.1, C43.1, D3.5 (VBUS), J4.A4_B9 (VBUS), J4.A9_B4 (VBUS); also elsewhere on the board

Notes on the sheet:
E-Paper Drive Circuit
Haptic Driver
E-Paper Display Connector
USB C Connector & ESD Protection
Fuel Gauge
Buttons

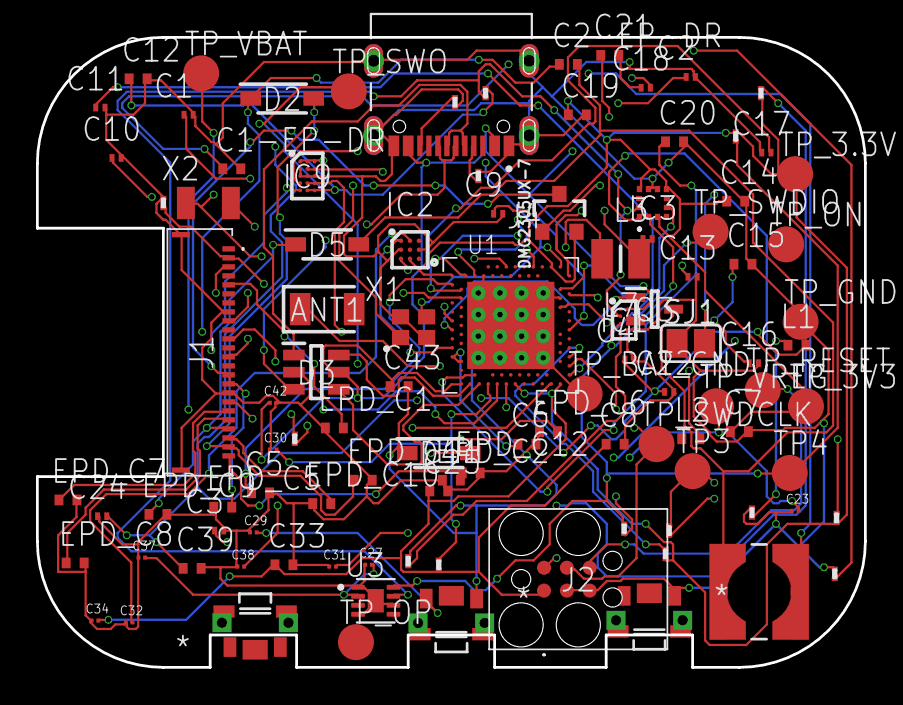
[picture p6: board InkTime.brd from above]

Board: 4 copper layers, 46.0 x 35.0 mm, 105 parts (0 on the bottom side), 71 nets.

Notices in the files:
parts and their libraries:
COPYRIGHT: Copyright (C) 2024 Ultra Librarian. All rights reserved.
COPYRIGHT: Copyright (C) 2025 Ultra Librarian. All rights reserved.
